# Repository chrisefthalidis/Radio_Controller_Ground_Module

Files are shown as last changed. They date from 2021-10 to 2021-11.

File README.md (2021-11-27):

This board is an embedded system, based on the STM32F411CCU6 microcontroller. It incorporates an nRF24L01+ radio
transceiver with an analog front-end (RFX2401C) for signal amplification. Inside the 'Hardware' folder, you will
find all the necessary PCB design files from KiCad. Inside the 'Firmware' folder, you will find all the relevant
HAL drivers generated by STM32CubeMX, as well as an nRF24L01+ SPI driver. This board is complementary to the Flight
Controller board that you will find on my GitHub page. The basic idea is that we read the value of the on-board 
potentiometer through an ADC via DMA and we transmit this value via radio to the Flight Controller, which in turn
controls the speed of the quadcopter's motors.

P.S. This board is not perfect in any way. It has some design mistakes, because it's one of my earlier boards, but
it WORKS fine. With each board that i design, i learn new stuff and keep getting better. If you have any questions
on how to use this board, please contact me at chrisefthalidis@gmail.com

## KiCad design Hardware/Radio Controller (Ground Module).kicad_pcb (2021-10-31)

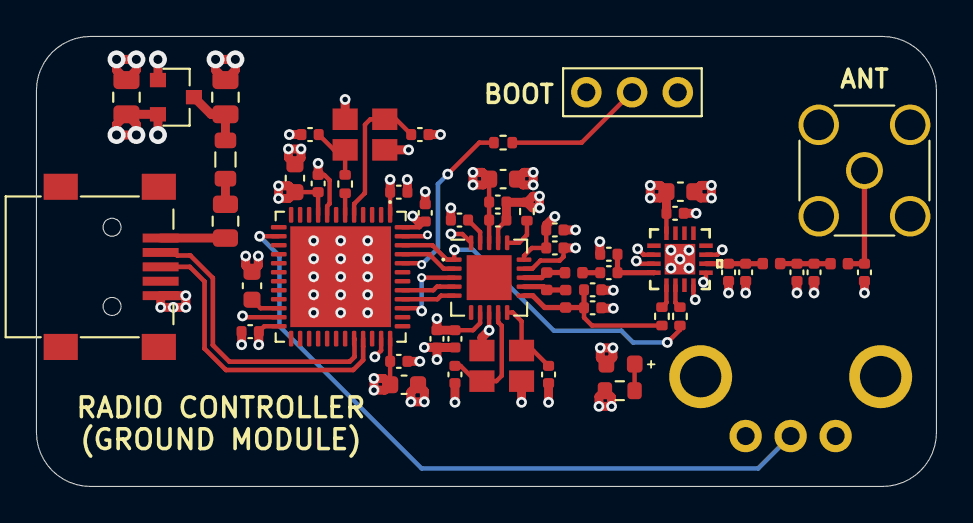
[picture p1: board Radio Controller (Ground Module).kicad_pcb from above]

Board: 4 copper layers, 50.0 x 25.0 mm, 57 parts (0 on the bottom side), 34 nets.

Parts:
C1, C2: 10uF; C_0805_2012Metric
C3, C24, C31: 4.7uF; C_0603_1608Metric
C4, C6, C8: 10nF; C_0402_1005Metric
C5, C7, C9: 1nF; C_0402_1005Metric
C10, C29: 1uF; C_0603_1608Metric
C11: 220pF; C_0402_1005Metric
C12: 4.7pF; C_0402_1005Metric
C13: 2.2nF; C_0402_1005Metric
C14, C20, C21, C22, C23: 1.5pF; C_0402_1005Metric
C15: 1pF; C_0402_1005Metric
C16: 33nF; C_0402_1005Metric
C17, C18, C32, C33: 12pF; C_0402_1005Metric
C19: 0.3pF; C_0402_1005Metric
C25, C26, C27, C28, C30: 100nF; C_0402_1005Metric
D1: Green LED; LED_0603_1608Metric
F1: Fuse; Fuse_0805_2012Metric
FB1: GZ2012D601TF; L_0805_2012Metric
J1: USB_B_Mini; USB_Mini-B_Lumberg_2486_01_Horizontal
J2: KH-SMA-KE8-G; SMA_Amphenol_132291_Vertical
J3: Conn_01x03; PinHeader_1x03_P2.54mm_Vertical
L1: 2.7nH; L_0402_1005Metric
L2: 8.2nH; L_0402_1005Metric
L3: 3.9nH; L_0402_1005Metric
L4, L5: 2.4nH; L_0402_1005Metric
R1: 330Ω; R_0603_1608Metric
R2, R3: 1ΚΩ; R_0402_1005Metric
R4: 22ΚΩ; R_0402_1005Metric
R5: 10ΚΩ; R_0402_1005Metric
R6: 47Ω; R_0402_1005Metric
RV1: R_POT; Potentiometer_Alps_RK09K_Single_Horizontal
U1: XC6206P332MR; SOT-23
U2: RFX2401C
U3: nRF24L01P; QFN-20-1EP_4x4mm_P0.5mm_EP2.5x2.5mm
U4: STM32F411CCUx; QFN-48-1EP_7x7mm_P0.5mm_EP5.6x5.6mm
Y1, Y2: X322516MLB4SI; Crystal_SMD_3225-4Pin_3.2x2.5mm

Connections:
+3V3: C2.1, C3.1, C4.1, C5.1, C6.1, C7.1, C8.1, C9.1, C10.1, C11.1, C24.1, C25.1, C26.1, C27.1, C28.1, C29.1, C30.1, J3.1, R1.1, RV1.1, U1.2, U2.16, U3.7, U3.15, U3.18, U4.1, U4.9, U4.24, U4.36, U4.48
/ADC_IN: RV1.2, U4.14
/ANT: C19.1, C20.1, L4.2, U2.10
/ANT1: L1.2, L2.1, U3.12
/ANT2: L2.2, L3.2, U3.13
/BOOT0: R5.1, U4.44
/CE: R3.1, U3.1, U4.46
/CSN: U3.2, U4.45
/LDO_VIN: C1.1, FB1.1, U1.3
/LED_RES: D1.2, R1.2
/MISO: U3.5, U4.40
/MOSI: U3.4, U4.41
/OSC_IN: C32.1, U4.5, Y2.1
/OSC_OUT: R6.2, U4.6
/RXEN: R3.2, U2.6
/SCK: U3.3, U4.39
/TXEN: R2.2, U2.5
/TXRX: C14.1, C15.1, U2.4
/USB_D+: J1.3, U4.33
/USB_D-: J1.2, U4.32
/VCAP1: C31.2, U4.22
/VDD_PA: C12.1, C13.1, L1.1, R2.1, U3.11
/XC1: C17.1, U3.10, Y1.1
/XC2: C18.1, U3.9, Y1.3
GND: C1.2, C2.2, C3.2, C4.2, C5.2, C6.2, C7.2, C8.2, C9.2, C10.2, C11.2, C12.2, C13.2, C15.2, C16.2, C17.2, C18.2, C19.2, C20.2, C21.2, C22.2, C23.2, C24.2, C25.2, C26.2, C27.2, C28.2, C29.2, C30.2, C31.1, C32.2, C33.2, D1.1, J1.5, J2.2, J3.3, R4.1, RV1.3, U1.1, U2.2, U2.3, U2.8, U2.9, U2.11, U2.17, U3.8, U3.14, U3.17, U3.20, U4.8, U4.23, U4.35, U4.47, U4.49, Y1.2, Y1.4, Y2.2, Y2.4
unnamed: C14.2, L3.1
unnamed: C16.1, U3.19
unnamed: C21.1, C22.1, L4.1, L5.2
unnamed: C23.1, J2.1, L5.1
unnamed: C33.1, R6.1, Y2.3
unnamed: F1.1, FB1.2
unnamed: J3.2, R5.2
unnamed: R4.2, U3.16
VBUS: F1.2, J1.1

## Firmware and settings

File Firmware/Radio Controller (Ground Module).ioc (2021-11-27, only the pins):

Mcu.UserName=STM32F411CCUx
PA11.Signal=USB_OTG_FS_DM
PA12.Signal=USB_OTG_FS_DP
PA4.Signal=ADCx_IN4
PB3.Signal=SPI3_SCK
PB4.Signal=SPI3_MISO
PB5.Signal=SPI3_MOSI
PB8.GPIO_Label=CSN
PB8.Signal=GPIO_Output
PB9.GPIO_Label=CE
PB9.Signal=GPIO_Output

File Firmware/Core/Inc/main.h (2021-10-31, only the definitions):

#define CSN_Pin GPIO_PIN_8
#define CSN_GPIO_Port GPIOB
#define CE_Pin GPIO_PIN_9
#define CE_GPIO_Port GPIOB

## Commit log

2021-11-27 Add DMA driver
2021-11-27 Add DMA in STM32CubeMX
2021-11-27 Update STM32CubeMX file
2021-11-27 Add DMA functionality

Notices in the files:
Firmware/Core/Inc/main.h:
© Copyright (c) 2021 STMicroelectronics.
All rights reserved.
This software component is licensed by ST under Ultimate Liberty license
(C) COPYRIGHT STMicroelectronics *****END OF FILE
